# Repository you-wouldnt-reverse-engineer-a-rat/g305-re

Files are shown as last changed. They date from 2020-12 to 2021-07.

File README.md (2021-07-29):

# g305-re

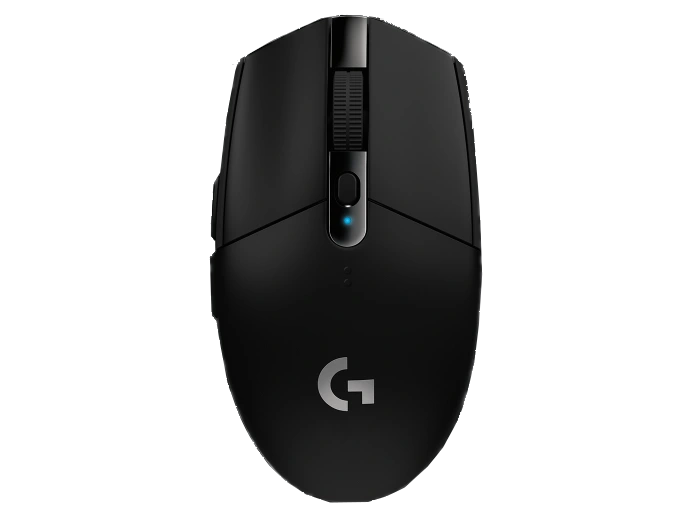
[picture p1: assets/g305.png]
g305


Reverse engineering of the [G305](https://www.logitechg.com/en-us/products/gaming-mice/g305-lightspeed-wireless-gaming-mouse.910-005280.html) mouse by [Logitech](https://www.logitech.com/en-us)

## Specs

| Spec | Range | Unit |
|:--|--:|:-:|
| DPI | 200 - 12000 | - |
| Max acceleration | 40 | g |
| Max Tracking speed | 400 | I/s |
| Report Rate | 1 | kHz |
| Processor Core | 32-bit ARM | - |
| Claimed Battery Life | 250 | hours |

### Eletrical Characteristics

| Characteristic | Range | Unit |
|:--|--:|:-:|
| Active Power | 10 | mW |
| Idle Power * | 4 | mW |
| Sleep Power ** | 200 | uW |
| Deep Sleep Power *** | ? |  |
| Turn On Voltage **** | 1.35 | V |
| Max Voltage ***** | 2.0 (3.6?) | V |

```
     * No movement
    ** After approximately 90 seconds idle
   *** After ~10 minutes of sleep? (to be measured)
  **** Below this voltage the device is consistently unable to start
 ***** The device can tolerate more (tested up to 5.5V),
but above 4.8V it seems to consume unusually high power during Deep Sleep,
and above 2.0V the main voltage bus (nominal 2.0V) follows the input voltage (the same appens with the led 3.7V bus) meaning it goes over
the normal opperating conditions, still unkown if it has any long term impact (cryomods is currently running a long term test on one), suspission is that it is generally safe.
```
`These are rough conservative approximations (though measured with fairly good equipment). Measurements on a single personal device.`

### Radio

Frequency range: 2.402-2.481 GHz
Modulation Technology: GFSK

PCB as populated a Ceramic chip Antenna capable of 2.4 to 2.4835GHz.

[FCC Documents](https://fccid.io/JNZMR0071) for the mouse.

### Expected Battery Life

| Battery | Weight [g] | Nominal Voltage [V] | Capacity [mAh] | Capacity [mWh] | Active Battery Life [h] |
|:--|--:|--:|--:|--:|--:|
| ALkaline LR6 (AA) | | 1.5 | 1800 – 2850 | 2700 - 4275 | 270 - 428 |
| ALkaline LR03 (AAA) | | 1.5 | 860 – 1200 | 1290 - 1800 | 129 - 180 |
| Lithium 14500 (AA) | | 3.6 | 600 - 840 (1600 @ 1.5V) | 2160 - 3024 (2400 @ 1.5V) | 216 - 302 |
| Lithium 10440 (AAA) | | 3.6 | 350 | 1260 | 126 |
| PR675 | 1.85 | 1.4 | 550 - 600 | 770 - 840 | 77 - 84 |
| Super Capacitor 70F | 18 | 2.7 | - | - | 5.83 |
| Super Capacitor 30F | 6.9 - 9.7 | 2.7 | - | - | 2.5 |

[source: AAA Battery](https://en.wikipedia.org/wiki/AAA_battery), [source: AA Battery](https://en.wikipedia.org/wiki/AA_battery)

## Receiver

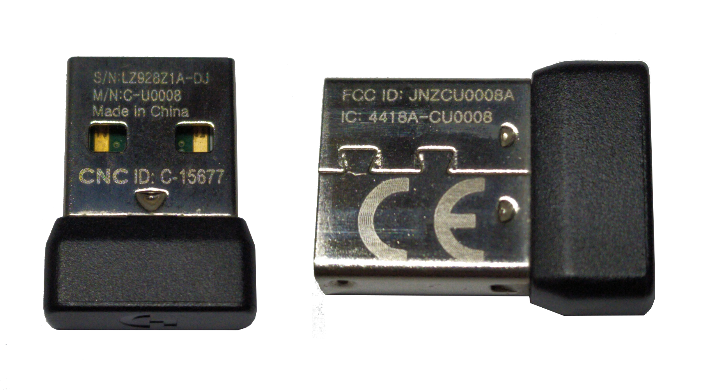
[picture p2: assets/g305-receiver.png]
g305-receiver


[FCC Documents](https://fccid.io/JNZCU0008A)

Frequencies: 2.402 to 2.481GHz

Modulations technology: GFSK

Antenna Type: Printed

MCU: TI CC2544

`Reverse engineering of the receiver is not planned`

## hardware

The hardware was traced in gimp, and can be analyzed in there too (everything is layered), file is [here](trace/g305.xcf).
`Whatch out, the top is mirrored!`

g305-re-bot
g305-re-top
g305-re-overlay

### Mechanical

CAD drawings of the G305 available in [cad](cad/)

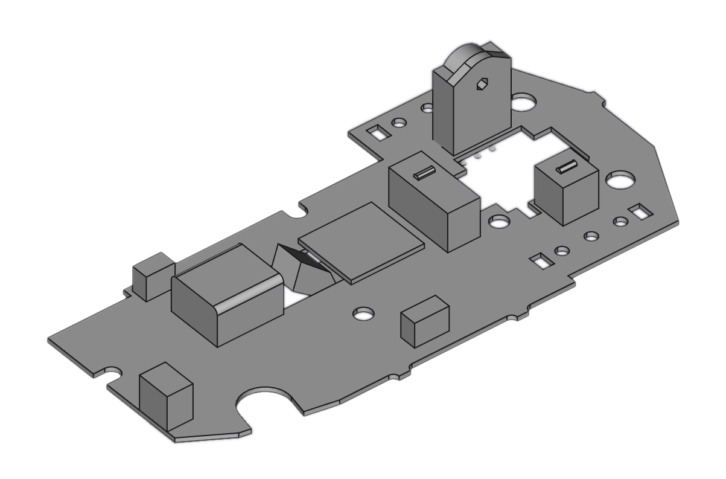
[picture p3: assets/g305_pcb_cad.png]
g305_pcb

credit to [inornate](https://www.thingiverse.com/inornate) on thingiverse.

### Components

The main board consists of:

 - The HERO sensor
 - A NRF52810 MCU in QFN-48
 - unidentified boost converter 1
 - unidentified boost converter 2
 - 3x unidentified mosfet
 - unidentified common anode RGB LED
 - chip antenna
 - 16MHz crystal?

### testpoints

The PCB contains the following testpoints:

testpoint | Funcion | Additional Info
:---: | :---: | :---:
TP1 | VIN + | Direct from battery 1.5V
TP2 | VIN - | Direct from battery
TP3 |  | Does not Exist?
TP4 |  | Does not Exist?
TP5 |  | Does not Exist?
TP6 | P0.04 | Unused Pin Breakout
TP7 |  | Does not Exist?
TP8 |  | Does not Exist?
TP9 |  | Does not Exist?
TP10 | GND |
TP11 | VDD |
TP12 | SWDIO |
TP13 | SWCLK |
TP14 | RESET |
TP15 | P0.22 | SWO?
TP16 | P0.08 | Unused Pin Breakout
TP17 | P0.09 | Unused Pin Breakout
TP18 | P0.10 | Unused Pin Breakout
TP19 | P0.29 | Unused Pin Breakout
TP20 | P0.30 | Unused Pin Breakout
TP21 | P0.31 | Unused Pin Breakout
TP22 | P0.27 | Unused Pin Breakout
TP23 | P0.28 | Unused Pin Breakout

### MCU

The MCU is a nRF52810 from nordicsemi, ARM Cortex M4
Package: QFN-48
Endianness of the MCU: Little Endian

Pin name | Function
:---: | :---:
P0.11 | CS
P0.12 | MOSI
P0.13 | MISO
P0.14 | SCLK
~ | ~
P0.15 | LMB
P0.16 | RMB
P0.17 | MMB
P0.18 | forward side button
P0.19 | back side button
P0.20 | dpi button
~ | ~
P0.23 | encoder pull up resistors (power saving)
P0.00 | wheel encoder
P0.01 | wheel encoder
~ | ~
P0.02 | battery analog input
P0.03 | 3.7V (RGB VDD) enable
~ | ~
P0.05 | red LED
P0.06 | green LED
P0.07 | blue LED

## firmware

Initially plans were made to break APPPROTECT and dump the firmware, but it appears logitech never enabled it (you ok? lol)

[firmware dumps](flash_dump/)

## Sensor

The G305 comes with a HERO sensor, made in house by logitech, based on the mercury.

A reverse engineering effort towards this sensor will be made in a separate repo [hero-re](https://github.com/perigoso/hero-re).

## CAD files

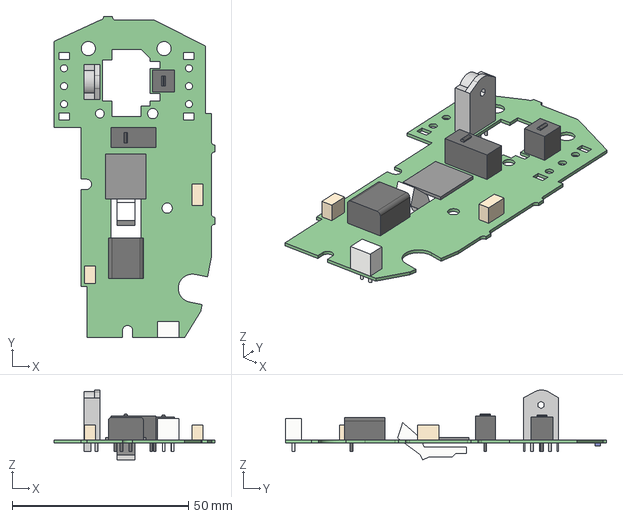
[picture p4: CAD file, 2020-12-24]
cad/G305_PCB.step
45.6 x 91.0 x 19.8 mm

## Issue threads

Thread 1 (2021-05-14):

More useful information

ifohancroft, 2021-05-14:
Here is some more information, that I find is helpful when trying to reverse engineer a mouse, that isn't present in the README:

Frequency range: 2.402-2.481 GHz (While the antena itself is capable of 2.4 to 2.4835GHz and the antena type is Ceramic chip Antenna)

Endianness of the MCU: Little Endian
The MCU is ARM Cortex M4 (the README does mention it's ARM but it doesn't mention that it's Cortex and which one, while the information can be found by looking for the datasheet for the MCU it's helpful to have it in the README).

Modulation Technology: GFSK

FCC Documents: https://fccid.io/JNZMR0071

I can't find information for the dongle because I can't find its FCC documents because I can't find its product number or FCC ID and the dongle shown in the FCC documents is for the G603 and I don't know if it comes with it or it whether the mouse has its own.

It would be useful if someone can provide USB captures in pcapng format of a firmware update of the mouse (even more useful if captures of the firmware update for two consecutive versions can be provided), as well as the update binaries.

perigoso, 2021-05-14:
Thank you, I will add this to the readme

ifohancroft, 2021-05-14:
Most welcome!

Unfortunately, I do not own the mouse. If you do, can you please tell me the following so I can hopefully dig up more information:
The dongle that it comes with - does it say G305 on it or does it actually say G603 like on the FCC internal photos? If the G305 does have its own dongle - what's its FCC ID or Model/Product Number (should be written on the dongle somewhere)?

It's worth checking out because there is a chance the dongle itself uses a different version or model MCU. For example, on my Viper Ultimate, it turned out that the mouse uses nRF52840, while the dongle uses nRF52810.

Btw, the idea of looking at the hardware side and not just the firmware, and actually overlaying the traces on top of the PCB in GIMP and labeling the pins and functions is brilliant! Kudos!

perigoso, 2021-05-14:
I think logitech uses the same dongles for a bunch of products, but I will check it when I can.
I also believe they have a couple different compatible dongles, that even use different brand mcus, like a TI, but I not 100% on this, anyway I doubt its the same mcu.

ifohancroft, 2021-05-14:
You never know :D My mouse's dongle actually uses the 810 but I am guessing they are using it just for the wireless and the USB itself is either external controller or a separate chip (or implemented in pure software but I doubt it).

Do let me know the number on it when you have a chance to check it out though.

perigoso, 2021-05-14:
@ifohancroft
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

perigoso, 2021-05-14:
Just like I said the receiver uses a TI chip, the CC2544

ifohancroft, 2021-05-14:
Thank you!

ifohancroft, 2021-05-14:
Here's more info about the receiver. Might be worth adding as well:

FCC Documents: https://fccid.io/JNZCU0008A
Frequencies: 2.402 to 2.481GHz
Modulations technology: GFSK
Antenna Type: Printed
MCU: TI CC2544

perigoso, 2021-05-14:
Merged this new info into the readme

ifohancroft, 2021-05-15:
@perigoso Sorry, I forgot to mention something important: Limited Results has recommended to me the ultimate version of the PocketGlitcher https://www.tindie.com/products/limitedresults/pocketglitcher/ as a tool-less and non-destructive way to circumvent APPROTECT and extract the firmware from nRF52* without the needing to open the device, solder to it, remove caps, etc.

However, the documentation needs to be read as I am not sure whether another tool isn't also required and what is the exact operating procedure.

perigoso, 2021-05-15:
thank, Ill be trying the hard way first though

ifohancroft, 2021-05-15:
Same :D

Closed 2021-05-14.

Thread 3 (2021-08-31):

New revision

madhan001, 2021-08-31:
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
Sent my mouse for RMA and got this, seems to be manufactured in July 2021

perigoso, 2021-08-31:
uh, interesting.

I believe this format is used on other logi models like the gpro wireless

madhan001, 2021-08-31:
Is there a possibility that this sensor is the hero 25K but limited in the firmware ? This mouse is running v68.2.21 firmware. Also, thanks for the voltage guide. Was able to mod my mouse to make it rechargeable with a TP4506 and a 300mAh lipo cell

madhan001, 2021-09-02:
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
Sensor with the sticker peeled back

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
Back of the PCB

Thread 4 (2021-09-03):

flashing firmware

ksoju, 2021-09-03:
I'm guessing that you're dumping/flashing the from the MCU firmware via some JTAG onto the test points possibly. Can you provide more information for us new to hardware on how to do this? From what i gather, SWDIO and SWCLK should be the ones (maybe there are more) and I'd need to solder wires to them and hook a programmer/debugger to dump/flash. Any specific tools maybe that'll make this process more seamless? Any pointers would be much appreciated. Thanks!

perigoso, 2021-09-03:
If you're just looking to play with the firmware we have dumped a couple you have access to in the repo.

As for dumping it yourself you're gonna some sort of arm capable programmer, i personally use a jlink clone. The debug protocol is "swd" (a form of jtag particular for arm processors).
The typical connections needed are:
TP10 - GND
TP11- VDD
TP12 - SWDIO
TP13 - SWCLK
TP14 - RESET
All test points are labeled and were reversed, there's a table in the readme. This particular set is on the front right of the pcb, next to the scroll wheel.

Good luck.

If you need anything do ask.

ksoju, 2021-09-04:
Thanks, this is awesome to know this. Might be something useful to put in the readme. I'm thinking of trying out something like q305 project by qsxcv but not the 8k polling but I will definitely peruse the firmware to see what can be tweaked.

Closed 2021-09-04.

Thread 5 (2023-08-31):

What's the part number of the LD5?

Katerang31, 2023-08-31:
i'm dying to know it cuz mine fell of after i smacked the mouse to the table. it works perfectly fine but the LED Indicator is dead or idk the upped thingy fell off and it's no longer workingg

Closed 2024-12-10.

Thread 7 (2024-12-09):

Can you dump Receiver firmware？

arcRE, 2024-12-09:
My Receiver Soc died,I want buy a new Soc chip to fix it,but I haven't the firmware.can you help me？
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

perigoso, 2024-12-09:
I haven't played with the receiver at all, so I don't have anything on hand. If I were to guess the SoC is probably read/debug protected and we won't be able to extract anything without some really clever RE.

Sorry...

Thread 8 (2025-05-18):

About reverse engineering

EasyNetDev, 2025-05-18:
Hello,

I found your github repository and I want to ask you some questions about the reverse engineering legality for USB Protocols, if you have any answers.

I'm working on a project to build a driver for Linux / MacOS using libusb for Logitech / Saitek Flight Instrument Panel, link [here](https://www.logitechg.com/en-us/products/flight/flight-simulator-instrument-panel.945-000027.html).

I had this device for a while on my desk and I couldn't find a way to use it on my flight Sim X-plane 12 under Linux, so I decided to reverse engineering the USB Protocol and to prove the device is 100% supported in Linux.

Here is a video with my driver which is working under Linux without issues: https://youtu.be/Njzi5Fmo44s?si=MZgFuzNcChHNN3pv

I did a reverse engineering over Logitech DrirectOut.exe and this device and I've found all commands necessary to initialize, send image to the device and control the LEDs S1-S6 + UP/DOWN.

I want to make it OpenSource, but I don't know what are law implications if I make it OpenSource.

Do you have any idea? I want to contribute to the Linux / MacOS community.

Kind regards,
EasyNetDev

perigoso, 2025-05-20:
I'm not a lawyer, so not legal advice, but if you reverse engineered without any insider information or based on leaked code (i.e. black box) and you didn't accept any agreements with re clauses to get the binaries, you should be in the clear, nothing explicitly illegal there, at worst it is a legal grey area

EasyNetDev, 2025-05-20:
Hi @perigoso,

Thank you. The reverse engineering I've done it 100% over the USB packet capture. Then using these captures I figured out each command with their fields.
I've recreated from scratch the source code and I've made a working driver for this device under Linux without any source leak or source decompilation, just analyzing the USB communication.

I'm trying to help Linux community as much as I can.

perigoso, 2025-05-20:
You should be perfectly fine then, with my understanding from personal experience

Closed 2025-05-20.

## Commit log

2020-12-24 Add CAD and local copy of g305 image
    [G305_PCB.step]
2021-05-14 add gimp trace
2021-05-14 add trace renders
